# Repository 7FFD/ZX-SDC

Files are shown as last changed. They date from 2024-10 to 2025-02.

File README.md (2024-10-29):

# ZX-SDC
Hardware version of z-controller (SD Card)

My motivation on creation this design was to avoid usage of CPLD and show that it's possible to design such controller with ICs.

This controller is intended to connect your ZX Spectrum / Clone with SD Card. That gives ability to copy files between SD Card with FAT16/32 to TRDOS (Beta Drive Interface), Nemo IDE and etc.

As an example, you can use FATALL file manager that runs from TRD.

## Technical information

This controller is almost fully compatible with original z-controller. There are couple of differences:
 - SD Card is always connected to power supply, besides it has power led connected to trigger to show state;
 - When /CS=1, means SD Card not selected, sending byte to data port is overwritten with 0xFF. It's a fix, because some SD Cards continue receiving input even after /CS becomes 1;

Control Port: 0x77
 - Bit 0: SD Card power On=1, Off=0;
 - Bit 1: SD Card /CS selected=0, deselected=1;
 - Rest bits are undefined;
   
Data Port: 0x57
 - Bit 0..7: Data byte to read/write; 

## Connection to ZX Spectrum Clones

Because current board design was done for ZXBUS, if you want to connect to your ZX Spectrum clone then you will need to solder adapter based on documentation for your computer.
Carefully check all signals, they are all important! As an example: /WAIT.

## Schematic preview
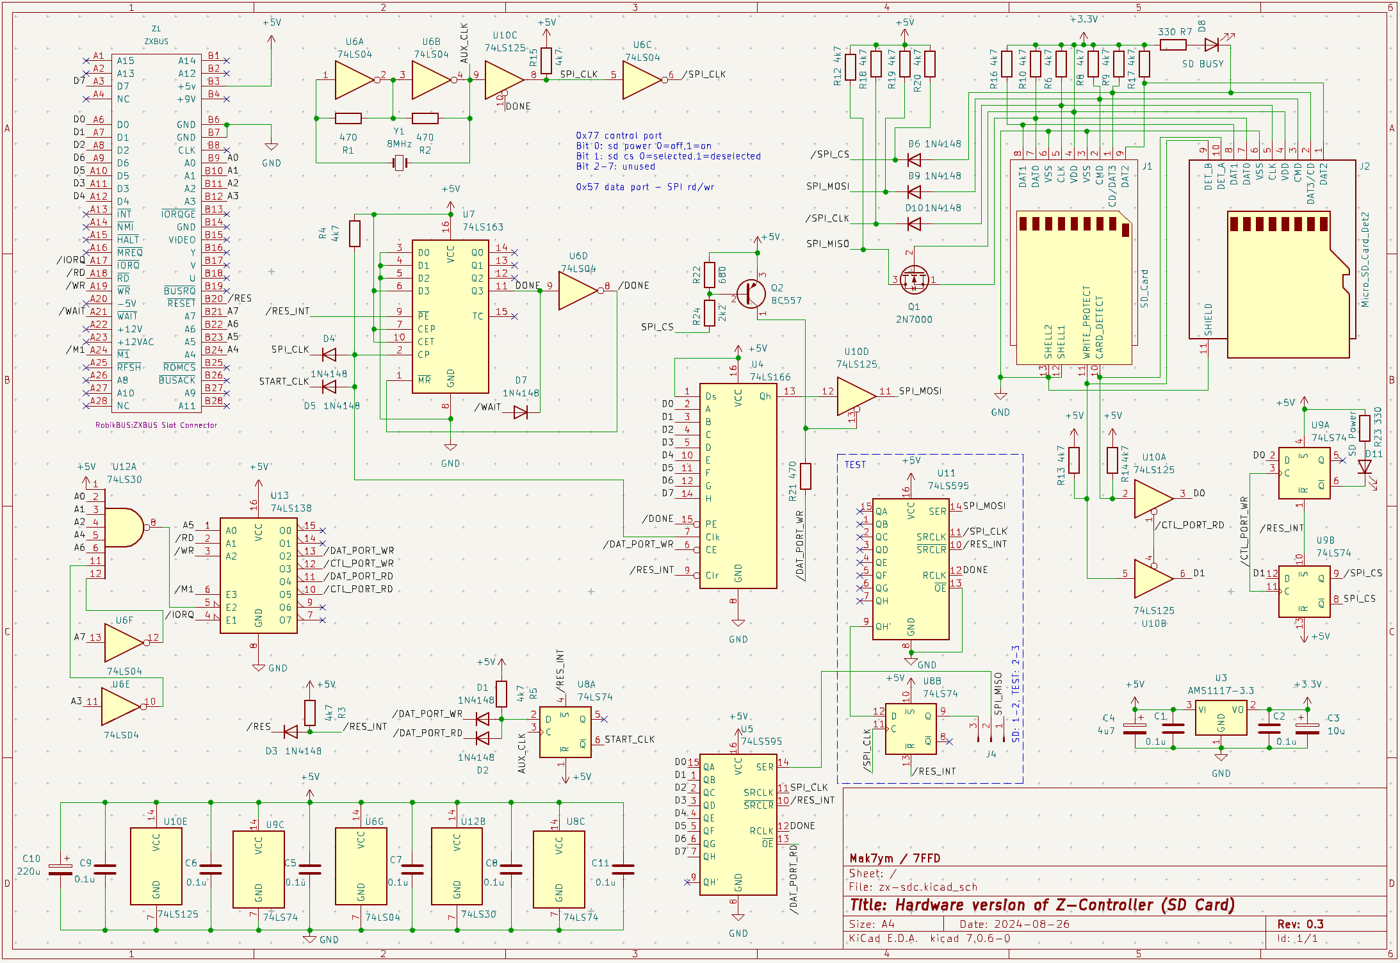
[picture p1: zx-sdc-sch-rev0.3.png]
Schematic, Rev 0.3


## Board preview
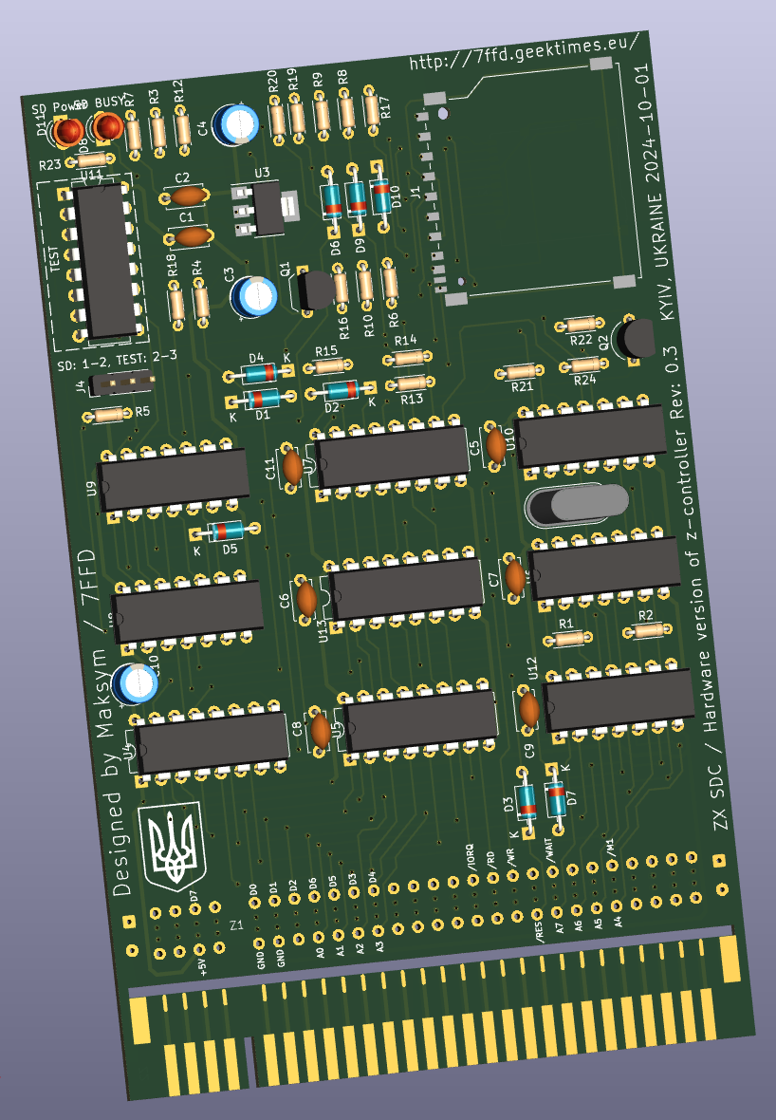
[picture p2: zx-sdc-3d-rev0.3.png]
Board, Rev 0.3


## Prototype
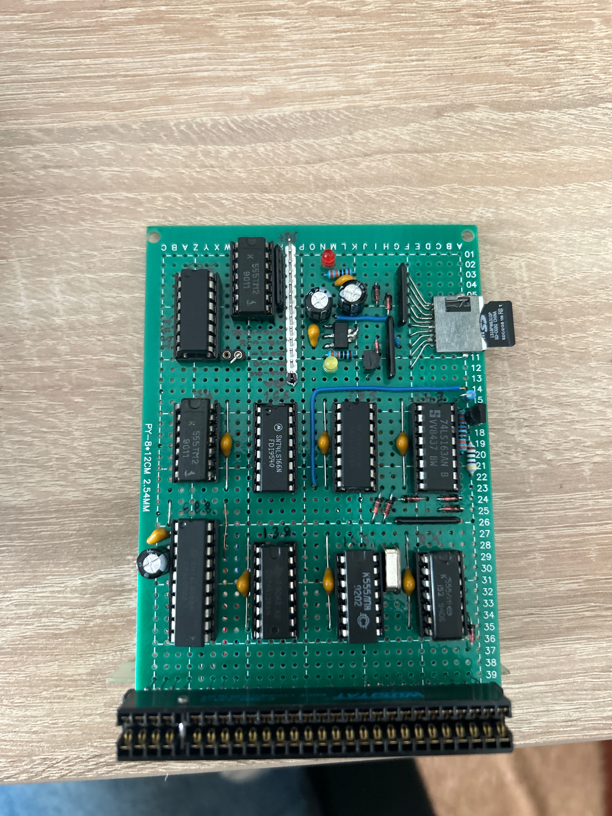
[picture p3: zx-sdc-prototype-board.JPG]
Prototype board


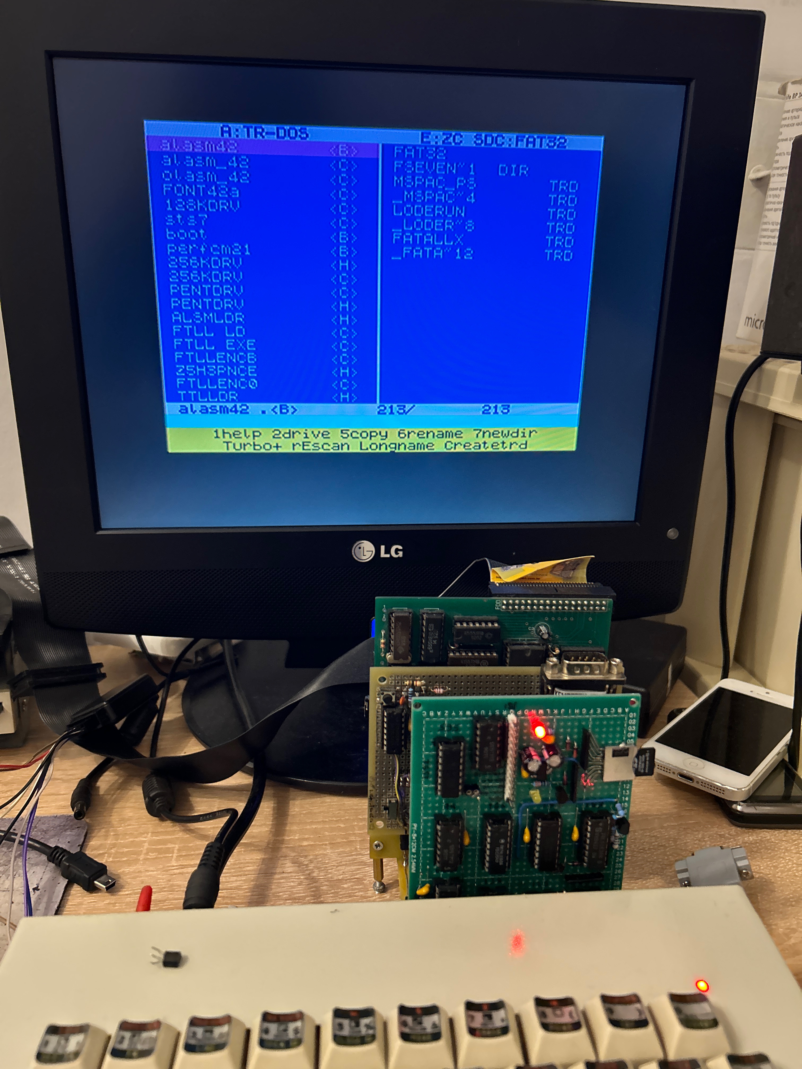
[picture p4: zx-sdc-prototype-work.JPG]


## Assembled and working board

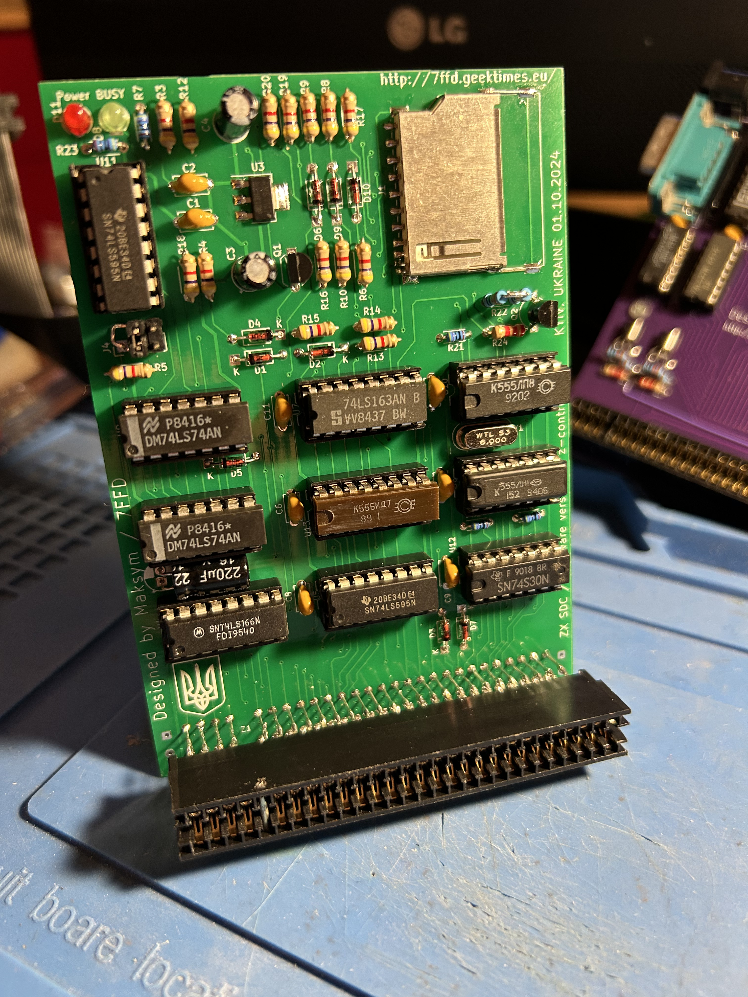
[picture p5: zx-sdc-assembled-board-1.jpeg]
Assembled board


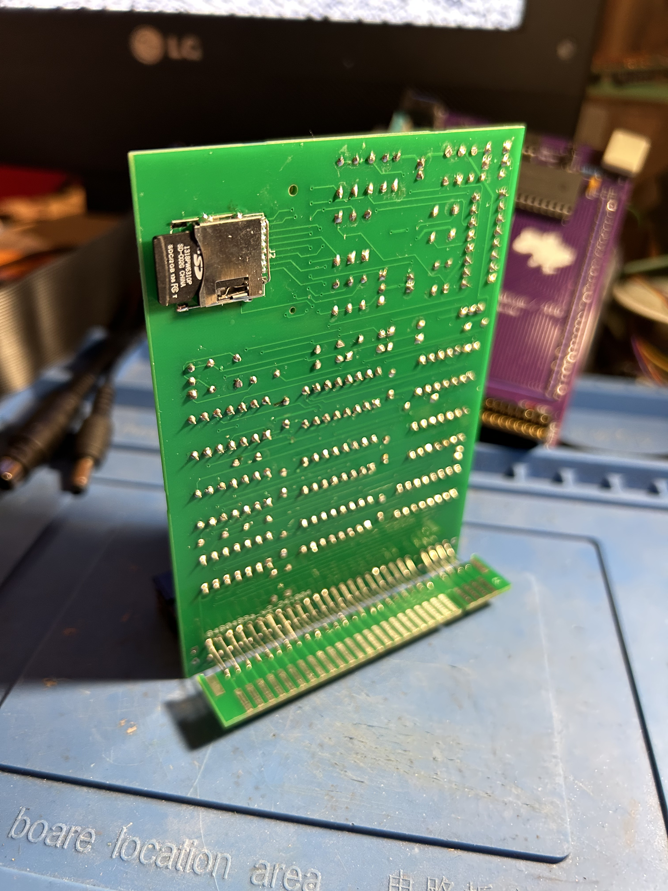
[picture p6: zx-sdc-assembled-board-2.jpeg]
Assembled board


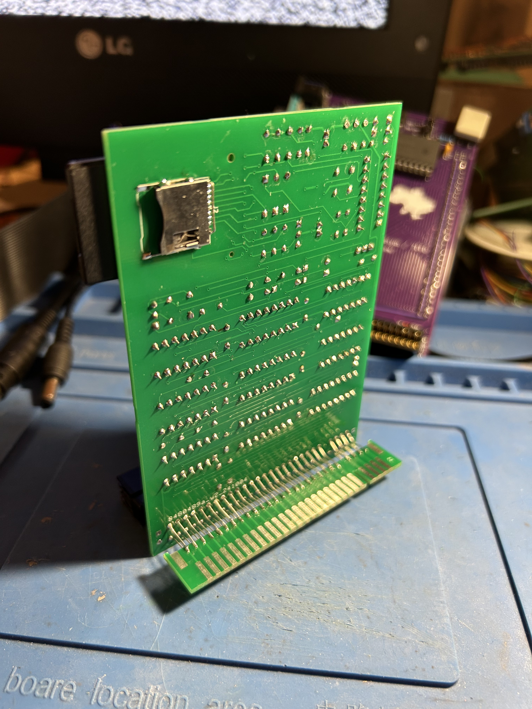
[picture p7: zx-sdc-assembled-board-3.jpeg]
Assembled board


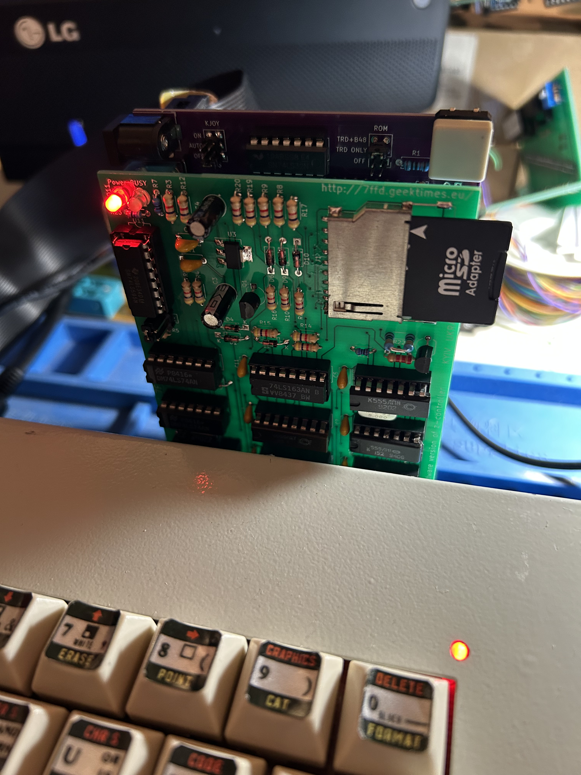
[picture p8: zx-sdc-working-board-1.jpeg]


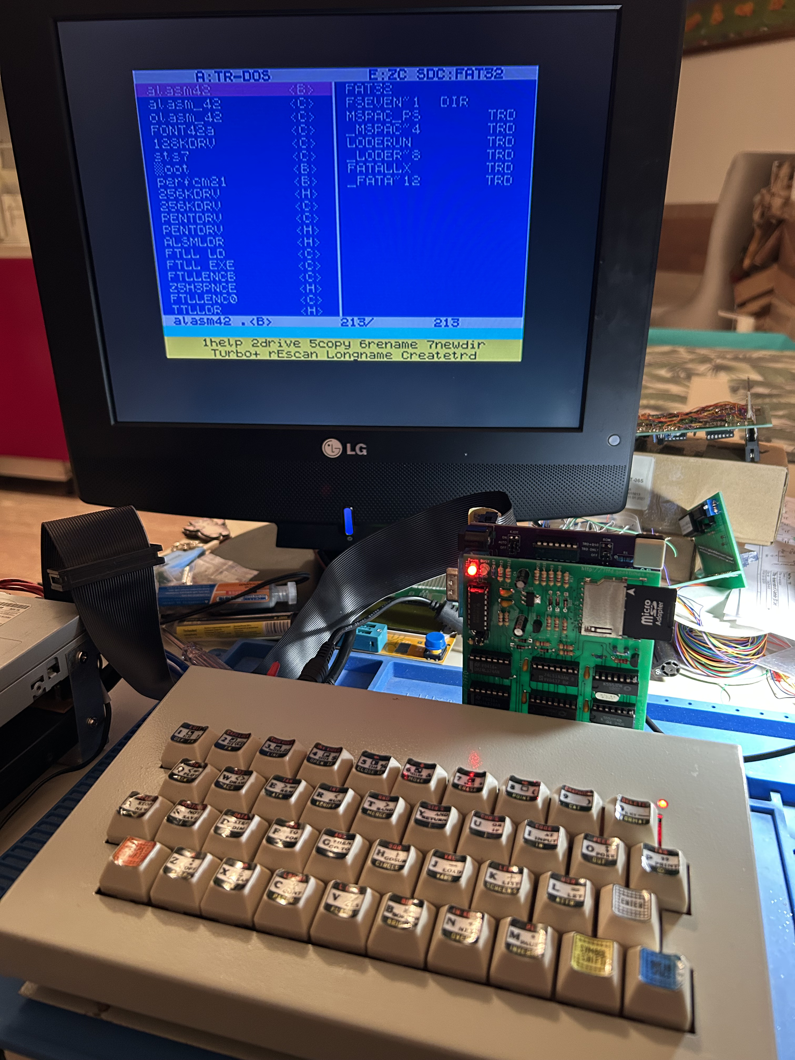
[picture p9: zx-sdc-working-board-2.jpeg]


## Note on assembling board

U11 and J4 has been added to the board for debugging purpose. Since board has been tested and doesn't need to be tuned if assembled correct, you can skip soldering U11 or use socket for it.
J4: 1-2 SD Card, 2-3 U11 Test IC connection

In case you decided to make sure that board assembled right and works correct, follow this checklist:
 1. Switch off computer
 2. Connect controller to ZXBUS Edge
 3. Remove SD Card if it was inserted at any slots
 4. Put jumper on J4 to 2-3
 5. Switch on computer - there are no leds should be ON
 6. Run commands from Basic:
    + "PRINT IN 87", expected result: 0
    + "PRINT IN 87", expected result: 255
    + "OUT 119,1", both leds must switch ON
    + "OUT 87,85"
    + "PRINT IN 87", expected result: 85
 7. Switch off computer
 8. Put jumper on J4 to 1-2
 9. Insert SD Card at any slot
 10. Switch on computer
 11. Run FATALL from ROM or from BDI
 12. SD Card should be detected and content will be shown on right panel

NOTE: SD Card must be formatted in FAT32/16!!!

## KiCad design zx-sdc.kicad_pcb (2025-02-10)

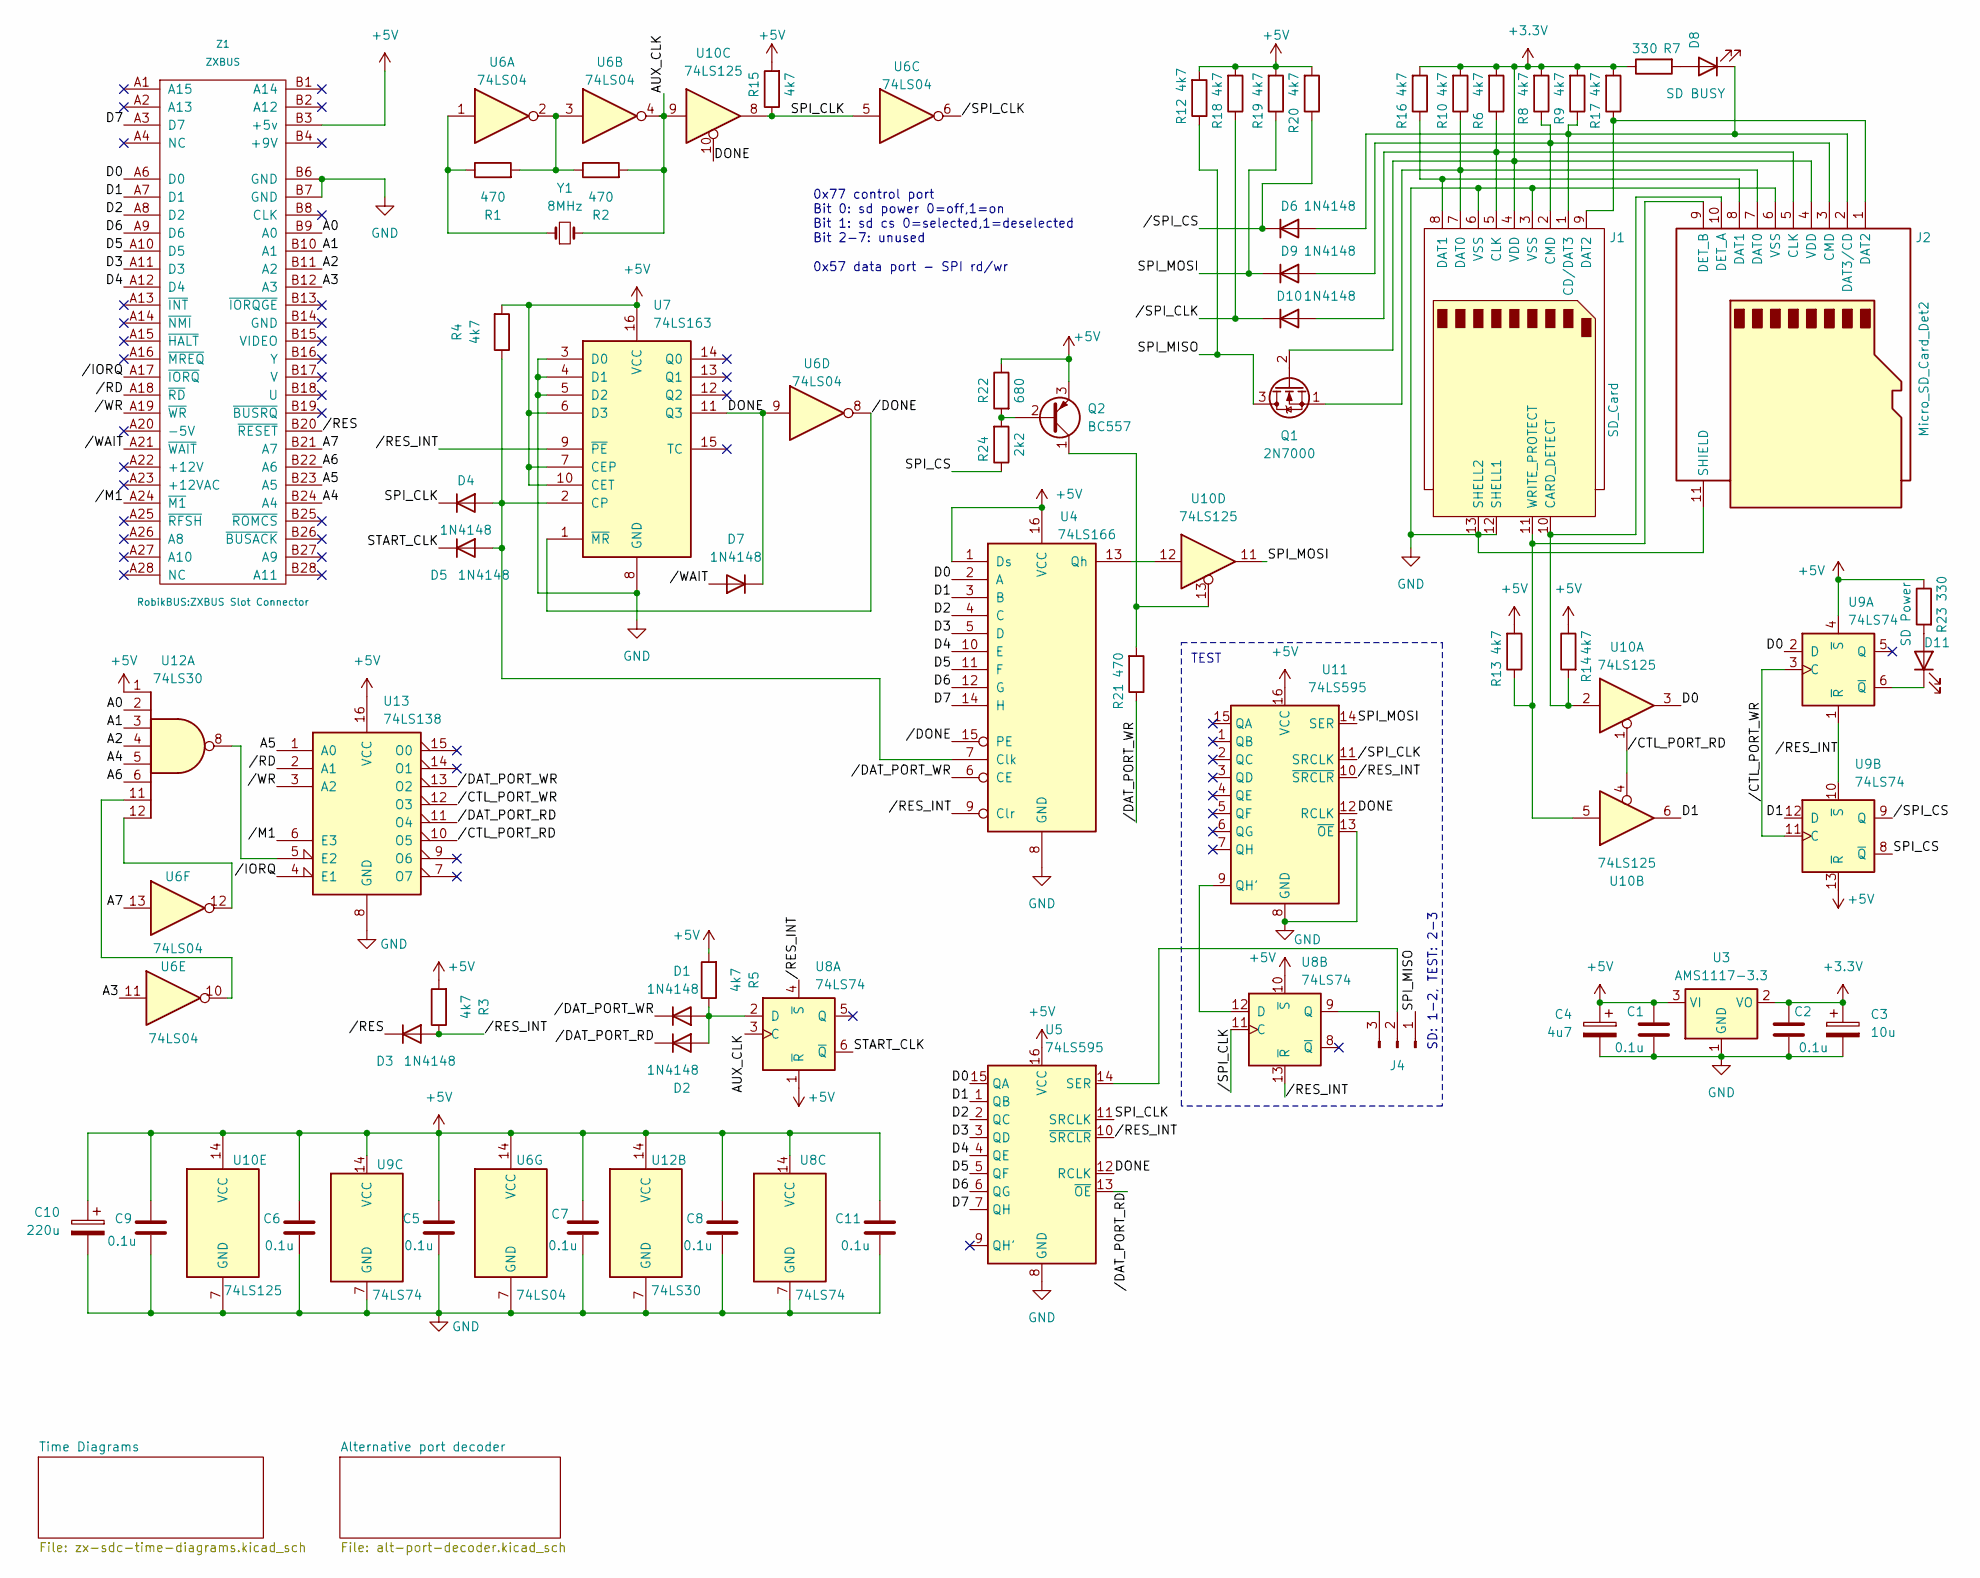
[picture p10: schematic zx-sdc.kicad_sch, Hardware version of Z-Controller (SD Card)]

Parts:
C1, C2, C5, C6, C7, C8, C9, C11: 0.1u; C_Disc_D4.7mm_W2.5mm_P5.00mm
C3: 10u; CP_Radial_D5.0mm_P2.00mm
C4: 4u7; CP_Radial_D5.0mm_P2.00mm
C10: 220u; CP_Radial_D5.0mm_P2.00mm
D1, D2, D3, D4, D5, D6, D7, D9, D10: 1N4148; D_DO-35_SOD27_P7.62mm_Horizontal
D8: SD BUSY; LED_D3.0mm
D11: SD Power; LED_D3.0mm
J1: SD_Card; SD_TE_2041021
J2: Micro_SD_Card_Det2; microSD_HC_Hirose_DM3AT-SF-PEJM5
J4: Conn_01x03_Pin; PinHeader_1x03_P2.54mm_Vertical
Q1: 2N7000; TO-92_Inline_Wide
Q2: BC557; TO-92_Inline_Wide
R1, R2, R21: 470; R_Axial_DIN0204_L3.6mm_D1.6mm_P5.08mm_Horizontal
R3, R4, R5, R6, R8, R9, R10, R12, R13, R14, R15, R16, R17, R18, R19, R20: 4k7; R_Axial_DIN0204_L3.6mm_D1.6mm_P5.08mm_Horizontal
R7, R23: 330; R_Axial_DIN0204_L3.6mm_D1.6mm_P5.08mm_Horizontal
R22: 680; R_Axial_DIN0204_L3.6mm_D1.6mm_P5.08mm_Horizontal
R24: 2k2; R_Axial_DIN0204_L3.6mm_D1.6mm_P5.08mm_Horizontal
U3: AMS1117-3.3; SOT-223-3_TabPin2
U4: 74LS166; DIP-16_W7.62mm
U5, U11: 74LS595; DIP-16_W7.62mm
U6: 74LS04; DIP-14_W7.62mm
U7: 74LS163; DIP-16_W7.62mm
U8, U9: 74LS74; DIP-14_W7.62mm
U10: 74LS125; DIP-14_W7.62mm
U12: 74LS30; DIP-14_W7.62mm
U13: 74LS138; DIP-16_W7.62mm
Y1: 8MHz; Crystal_HC18-U_Vertical
Z1: ZXBUS; ZXBUS Slot Connector

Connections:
+3.3V: C2.1, C3.1, J1.4 (VDD), J2.4 (VDD), Q1.2 (G), R6.2, R7.1, R8.2, R9.2, R10.2, R16.2, R17.2, U3.2 (VO)
+5V: C1.1, C4.1, C5.1, C6.1, C7.1, C8.1, C9.1, C10.1, C11.1, Q2.3 (E), R3.2, R4.2, R5.2, R12.2, R13.2, R14.1, R15.2, R18.2, R19.2, R20.2, R22.1, R23.1, U3.3 (VI), U4.1 (Ds), U4.16 (VCC), U5.16 (VCC), U6.14 (VCC), U7.6 (D3), U7.7 (CEP), U7.10 (CET), U7.16 (VCC), U8.1 (~R), U8.10 (~S), U8.14 (VCC), U9.4 (~S), U9.13 (~R), U9.14 (VCC), U10.14 (VCC), U11.16 (VCC), U12.1, U12.14 (VCC), U13.16 (VCC), Z1.B3 (+5v)
/A0: U12.2, Z1.B9 (A0)
/A1: U12.3, Z1.B10 (A1)
/A2: U12.4, Z1.B11 (A2)
/A3: U6.11, Z1.B12 (A3)
/A4: U12.5, Z1.B24 (A4)
/A5: U13.1 (A0), Z1.B23 (A5)
/A6: U12.6, Z1.B22 (A6)
/A7: U6.13, Z1.B21 (A7)
/AUX_CLK: R2.2, U6.4, U8.3 (C), U10.9, Y1.2
/D0: U4.2 (A), U5.15 (QA), U9.2 (D), U10.3, Z1.A6 (D0)
/D1: U4.3 (B), U5.1 (QB), U9.12 (D), U10.6, Z1.A7 (D1)
/D2: U4.4 (C), U5.2 (QC), Z1.A8 (D2)
/D3: U4.5 (D), U5.3 (QD), Z1.A11 (D3)
/D4: U4.10 (E), U5.4 (QE), Z1.A12 (D4)
/D5: U4.11 (F), U5.5 (QF), Z1.A10 (D5)
/D6: U4.12 (G), U5.6 (QG), Z1.A9 (D6)
/D7: U4.14 (H), U5.7 (QH), Z1.A3 (D7)
/DONE: D7.1 (K), U5.12 (RCLK), U6.9, U7.11 (Q3), U10.10, U11.12 (RCLK)
/SPI_CLK: D4.1 (K), R15.1, U5.11 (SRCLK), U6.5, U10.8
/SPI_CS: R24.1, U9.8 (~Q)
/SPI_MISO: J4.1, Q1.3 (D), R12.1
/SPI_MOSI: D9.1 (K), R19.1, U10.11, U11.14 (SER)
/START_CLK: D5.1 (K), U8.6 (~Q)
//CTL_PORT_RD: U10.1, U10.4, U13.10 (O5)
//CTL_PORT_WR: U9.3 (C), U9.11 (C), U13.12 (O3)
//DAT_PORT_RD: D2.1 (K), U5.13 (~OE), U13.11 (O4)
//DAT_PORT_WR: D1.1 (K), R21.1, U4.6 (CE), U13.13 (O2)
//DONE: U4.15 (PE), U6.8, U7.1 (~MR)
//IORQ: U13.4 (E1), Z1.A17 (~IORQ)
//M1: U13.6 (E3), Z1.A24 (~M1)
//RD: U13.2 (A1), Z1.A18 (~RD)
//RES: D3.1 (K), Z1.B20 (~RESET)
//RES_INT: D3.2 (A), R3.1, U4.9 (Clr), U5.10 (~SRCLR), U7.9 (~PE), U8.4 (~S), U8.13 (~R), U9.1 (~R), U9.10 (~S), U11.10 (~SRCLR)
//SPI_CLK: D10.1 (K), R18.1, U6.6, U8.11 (C), U11.11 (SRCLK)
//SPI_CS: D6.1 (K), R20.1, U9.9 (Q)
//WAIT: D7.2 (A), Z1.A21 (~WAIT)
//WR: U13.3 (A2), Z1.A19 (~WR)
GND: C1.2, C2.2, C3.2, C4.2, C5.2, C6.2, C7.2, C8.2, C9.2, C10.2, C11.2, J1.3 (VSS), J1.6 (VSS), J1.12 (SHELL1), J1.13 (SHELL2), J2.6 (VSS), J2.11 (SHIELD), U3.1 (GND), U4.8 (GND), U5.8 (GND), U6.7 (GND), U7.3 (D0), U7.4 (D1), U7.5 (D2), U7.8 (GND), U8.7 (GND), U9.7 (GND), U10.7 (GND), U11.8 (GND), U11.13 (~OE), U12.7 (GND), U13.8 (GND), Z1.B6 (GND), Z1.B7 (GND)
unnamed: D1.2 (A), D2.2 (A), R5.1, U8.2 (D)
unnamed: D4.2 (A), D5.2 (A), R4.1, U4.7 (Clk), U7.2 (CP)
unnamed: D6.2 (A), D8.1 (K), J1.1 (CD/DAT3), J2.2 (DAT3/CD), R9.1
unnamed: D8.2 (A), R7.2
unnamed: D9.2 (A), J1.2 (CMD), J2.3 (CMD), R8.1
unnamed: D10.2 (A), J1.5 (CLK), J2.5 (CLK), R6.1
unnamed: D11.2 (A), R23.2
unnamed: D11.1 (K), U9.6 (~Q)
unnamed: J1.10 (CARD_DETECT), J2.10 (DET_A), R14.2, U10.2
unnamed: J1.7 (DAT0), J2.7 (DAT0), Q1.1 (S), R10.1
unnamed: J1.8 (DAT1), J2.8 (DAT1), R16.1
unnamed: J1.9 (DAT2), J2.1 (DAT2), R17.1
unnamed: J1.11 (WRITE_PROTECT), J2.9 (DET_B), R13.1, U10.5
unnamed: J4.2, U5.14 (SER)
unnamed: J4.3, U8.9 (Q)
unnamed: Q2.2 (B), R22.2, R24.2
unnamed: Q2.1 (C), R21.2, U10.13
unnamed: R1.1, U6.1, Y1.1
unnamed: R1.2, R2.1, U6.2, U6.3
unnamed: U4.13 (Qh), U10.12
unnamed: U8.12 (D), U11.9 (QH')
unnamed: U6.10, U12.11
unnamed: U6.12, U12.12
unnamed: U12.8, U13.5 (E2)

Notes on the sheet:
SD: 1-2, TEST: 2-3
TEST
0x77 control port Bit 0: sd power 0=off,1=on Bit 1: sd cs 0=selected,1=deselected Bit 2-7: unused 0x57 data port - SPI rd/wr

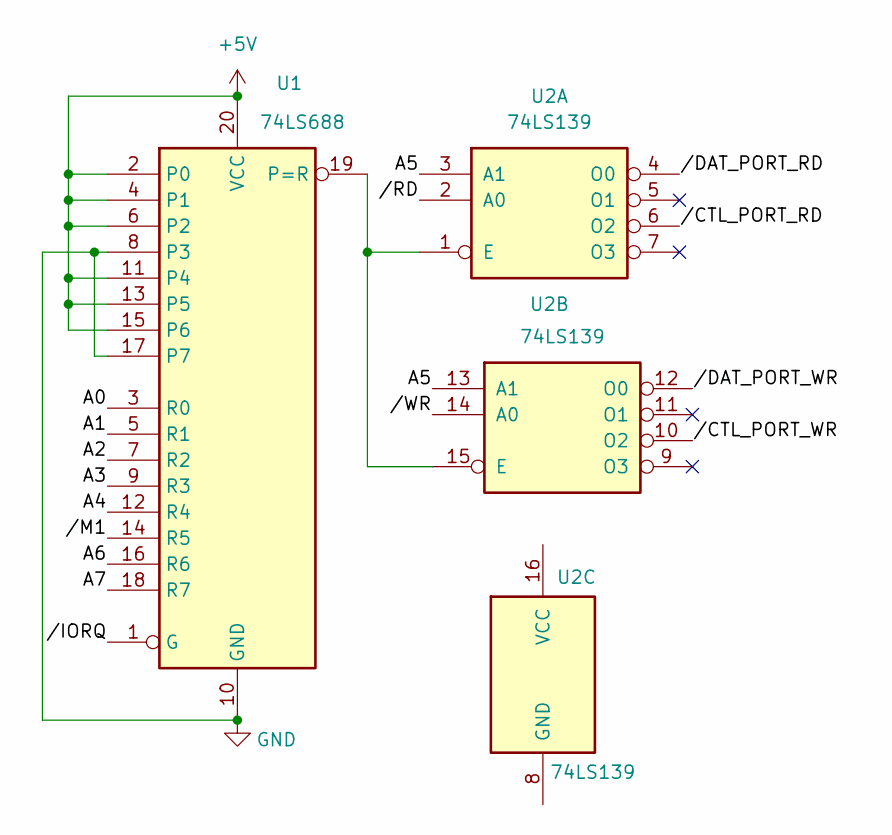
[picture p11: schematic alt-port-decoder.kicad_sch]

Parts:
U1: 74LS688
U2: 74LS139

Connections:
unnamed: U1.8 (P3), U1.10 (GND), U1.17 (P7)
unnamed: U1.2 (P0), U1.4 (P1), U1.6 (P2), U1.11 (P4), U1.13 (P5), U1.15 (P6), U1.20 (VCC)
unnamed: U1.19 (P=R), U2.1 (E), U2.15 (E)
unnamed: U2.3 (A1), U2.13 (A1)

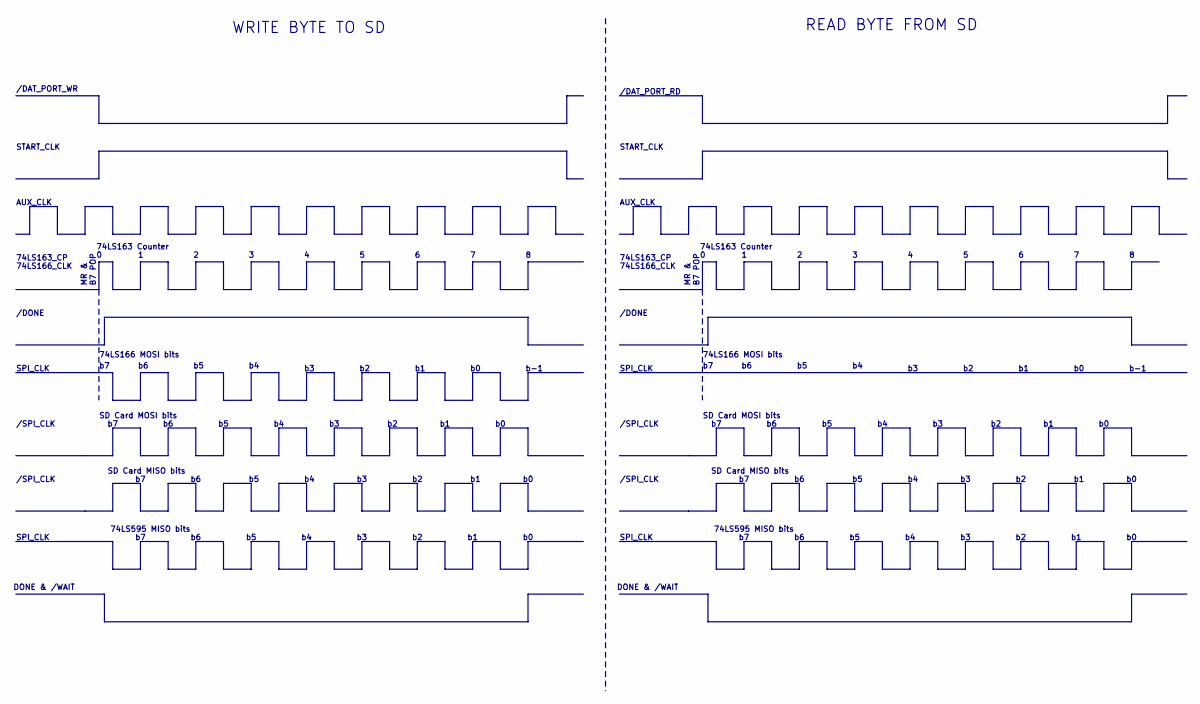
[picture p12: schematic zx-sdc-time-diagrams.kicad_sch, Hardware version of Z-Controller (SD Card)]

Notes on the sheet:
/DONE
74LS166 MOSI bits
b-1
READ BYTE FROM SD
DONE & /WAIT
SPI_CLK
WRITE BYTE TO SD
74LS166_CLK
74LS595 MISO bits
/SPI_CLK
START_CLK
AUX_CLK
SD Card MOSI bits
74LS163 Counter
/DAT_PORT_WR
SD Card MISO bits
/DAT_PORT_RD
74LS163_CP
MR & B7 POP

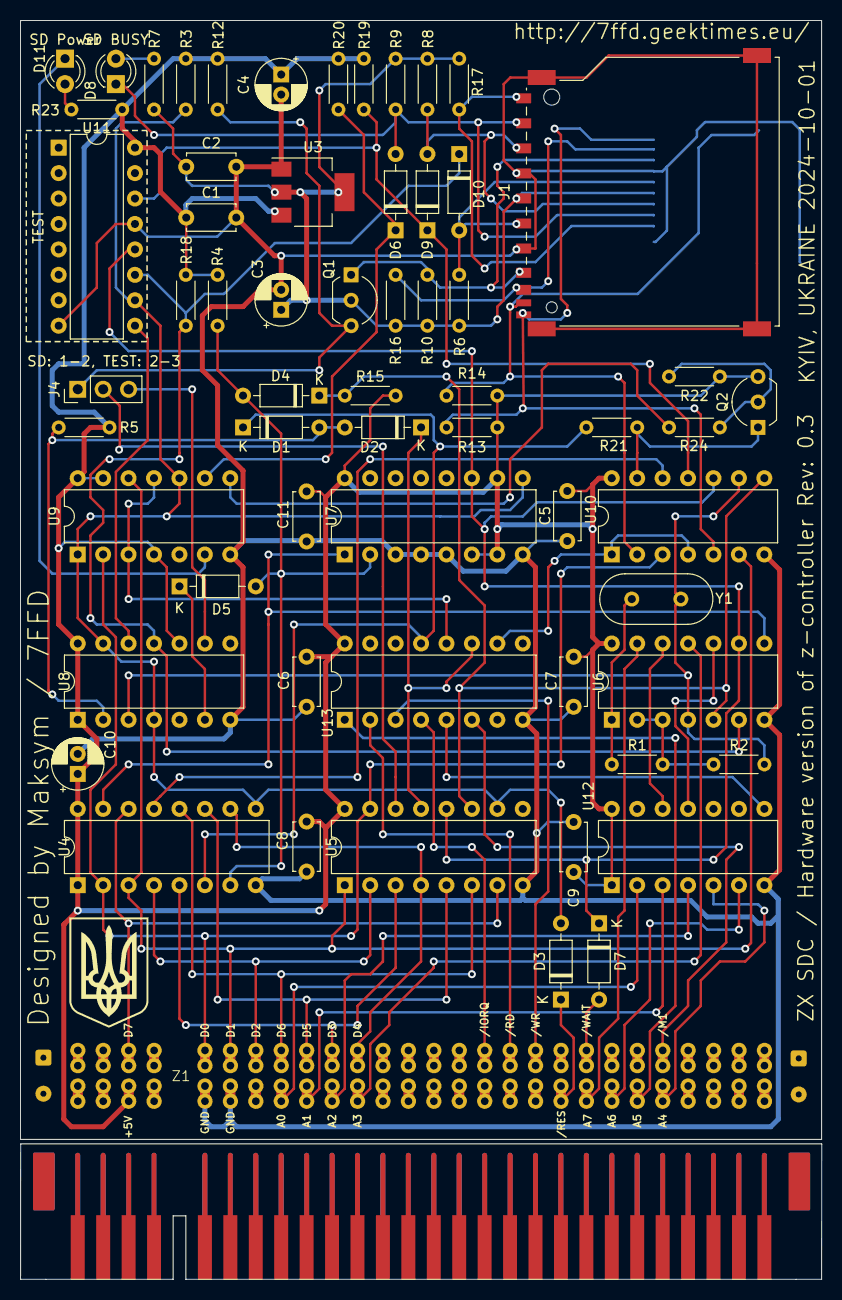
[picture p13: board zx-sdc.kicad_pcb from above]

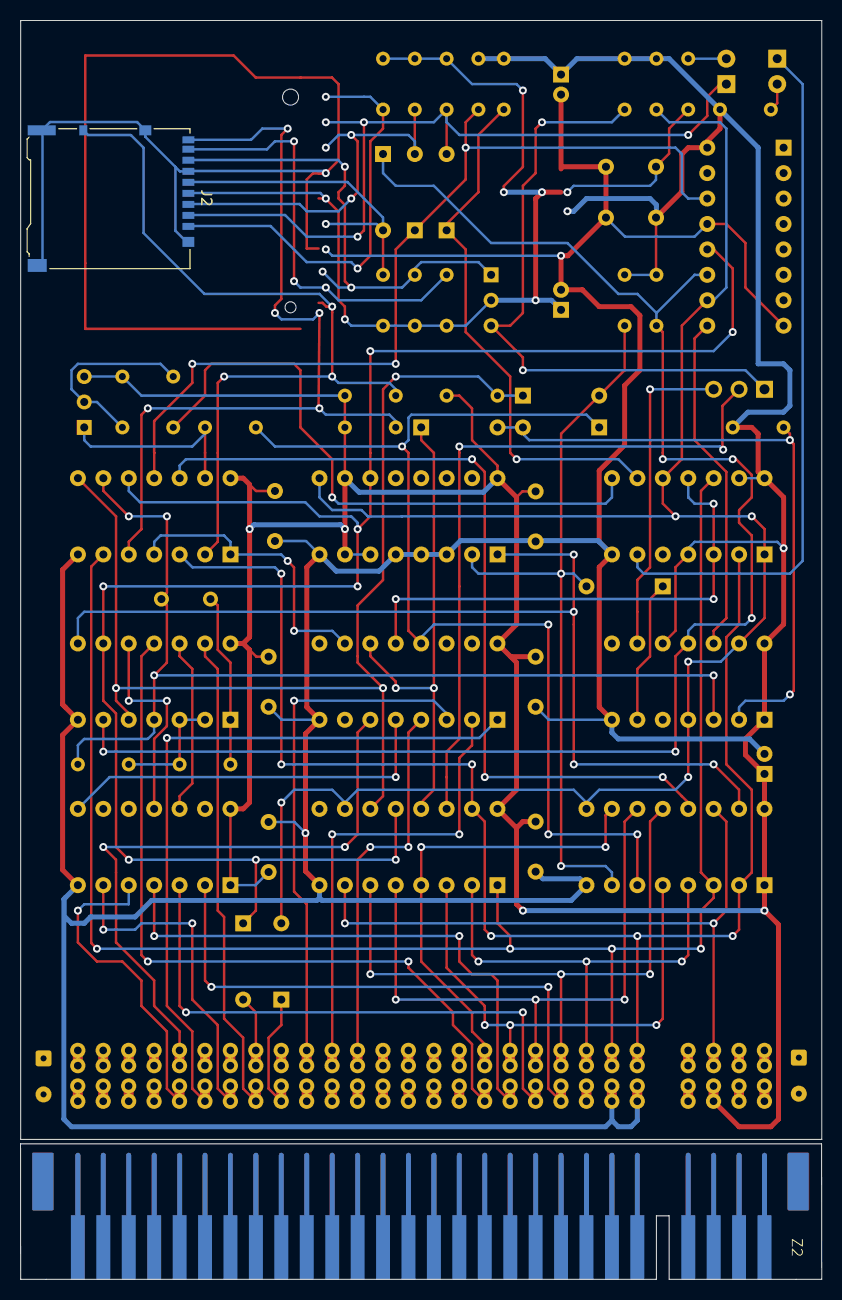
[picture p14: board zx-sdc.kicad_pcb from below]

Board: 2 copper layers, 80.0 x 125.7 mm, 65 parts (2 on the bottom side), 64 nets.

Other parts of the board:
UA CoA: UA CoA 8x11mm
Z2: ZXBUS

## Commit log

2024-10-03 Started ZX-SDC project, hardware version of Z-Controller
    [zx-sdc-time-diagrams.kicad_sch, zx-sdc.kicad_pcb, zx-sdc.kicad_sch]
2024-10-03 - added time diagram - created backup v0.1 - created backup v0.2 - added various changes
    [zx-sdc-time-diagrams.kicad_sch, zx-sdc-v0.1.kicad_sch, zx-sdc-v0.2.kicad_sch]
2024-10-03 preparation for board design
    [zx-sdc.kicad_sch]
2024-10-03 completed design of ZX SDC
    [zx-sdc.kicad_pcb, zx-sdc.kicad_sch]
2024-10-03 refinings & last cuts
    [alt-port-decoder.kicad_sch, zx-sdc.kicad_pcb, zx-sdc.kicad_sch]
2024-10-03 fixed revision number
    [zx-sdc.kicad_pcb]
2024-10-03 fixed and annotated SD/TEST jumpers
    [zx-sdc.kicad_pcb, zx-sdc.kicad_sch]
2024-10-03 Added schematic and 3d view for readme
2024-10-03 Replaced schematic file with fixes
2024-10-03 added photos of working prototype
2024-10-27 Added assembled board and run tests
2025-02-10 moved microsd slot close to edge
    [zx-sdc.kicad_pcb]
